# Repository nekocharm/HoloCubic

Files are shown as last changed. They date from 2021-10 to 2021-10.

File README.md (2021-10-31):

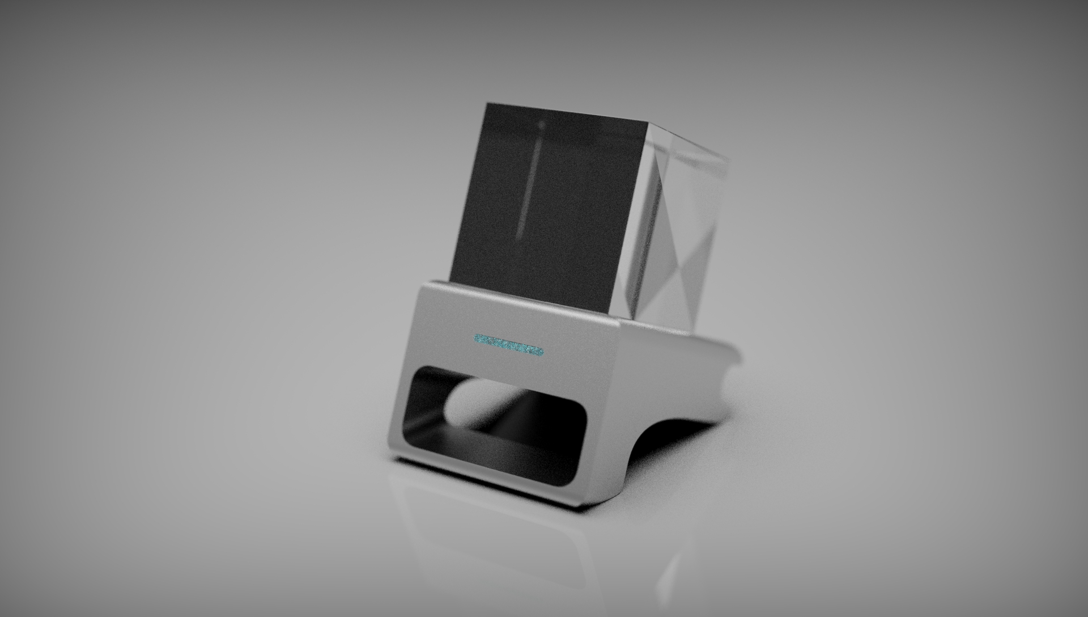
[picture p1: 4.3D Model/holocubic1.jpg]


# HoloCubic--多功能透明显示屏桌面站

**视频介绍：** https://www.bilibili.com/video/BV1VA411p7MD/

## 0. 关于本项目

本项目是从[稚晖君](https://github.com/peng-zhihui/HoloCubic)的基础上编写的，程序写的很乱。以下内容有所删改。

本项目的硬件方案是基于`ESP32PICO-D4`的，乐鑫的一个很实用的MCU芯片，由于采用了SiP封装是的PCBA整板面积能做到一个硬币大小；软件方面主要是基于`lvgl-GUI`库，我移植了ST7789 1.3寸`240x240`分辨率屏幕的显示屏驱动，同时将`MPU6050`作为输入设备通过感应的方式模拟编码器键值来交互。

## 1. 硬件打样说明

**PCB打样的话暂时没发现有啥需要特别注意的。** PCB文件可以直接拿去工厂打样，两层板很便宜，器件BOM的话也都是比较常用的，整板成本在50元以内。

**本项目里只有metal版本的PCB和模型**。我使用了这个版本的模型故删掉了其他版本的模型。

**我觉得RGB没有用就把RGB给去掉了，还把环境光传感器放在了前面，**不过最后我也没用环境光传感器，感觉用途不大，~~我终于知道为什么稚晖君把环境光传感器给去掉了。~~

## 2. 固件编译说明

固件框架主要基于Arduino开发完成，玩过Arduino的基本没有上手难度了，把Firmware/Libraries里面的库安装到Arduino库目录（如果你用的是Arduino IDE的话）即可。

> 我使用的是Visual Studio Code里的platformIO插件。

**然后这里需要修改一个官方库文件才能正常使用：**

首先肯定得安装ESP32的Arduino支持包（百度有海量教程），然后在安装的支持包的`esp32\hardware\esp32\1.0.4\libraries\SPI\src\SPI.cpp`文件中，**修改以下代码中的MISO为26**：

    if(sck == -1 && miso == -1 && mosi == -1 && ss == -1) {
        _sck = (_spi_num == VSPI) ? SCK : 14;
        _miso = (_spi_num == VSPI) ? MISO : 12; // 需要改为26
        _mosi = (_spi_num == VSPI) ? MOSI : 13;
        _ss = (_spi_num == VSPI) ? SS : 15;
这是因为，硬件上连接屏幕和SD卡分别是用两个硬件SPI，其中HSPI的默认MISO引脚是12，而12在ESP32中是用于上电时设置flash电平的，上电之前上拉会导致芯片无法启动，因此我们将默认的引脚替换为26。

> 也可以通过设置芯片熔丝的方式解决这个问题，不过那样的操作是一次性不可逆的，不建议这么玩。

**天气API**用的是心知天气，key我是保存在内存卡里然后读出来。

**内存卡**里具体要放哪些文件可以从程序中看出，内容太多就不放到GitHub上了。

**字体文件**是使用外部字库，可以找自己喜欢的字体用[LvglFontTool](http://www.lfly.xyz/forum.php)转换为bin文件。

## 3. Visual Studio模拟器 & 图片转换脚本

在`Software`文件夹中包含了一个Visual Studio的工程，用VS打开（需要安装C++开发组件）后可以在电脑上模拟LVGL的界面效果，改好之后代码粘贴到Arduino固件那边就可以完成界面移植。

> 这样省的每次修改都要重新交叉编译Arduino的固件，提升开发效率。

`HoloCubic`文件夹下是我用Qt6写的一个上位机软件，可以改WiFi密码等。

> release文件夹里有打包好的软件。

## 4. 关于分光棱镜

我用的时25.4mm x 25.4mm x 25.4mm的棱镜，淘宝应该可以搜到，单个价格80元左右。

分光棱镜的固定比较麻烦，OCA胶水太难粘了，揭下来的时候还弄坏了一个屏幕，我推荐使用UV胶，可以保证没有气泡。

## 5.实物图

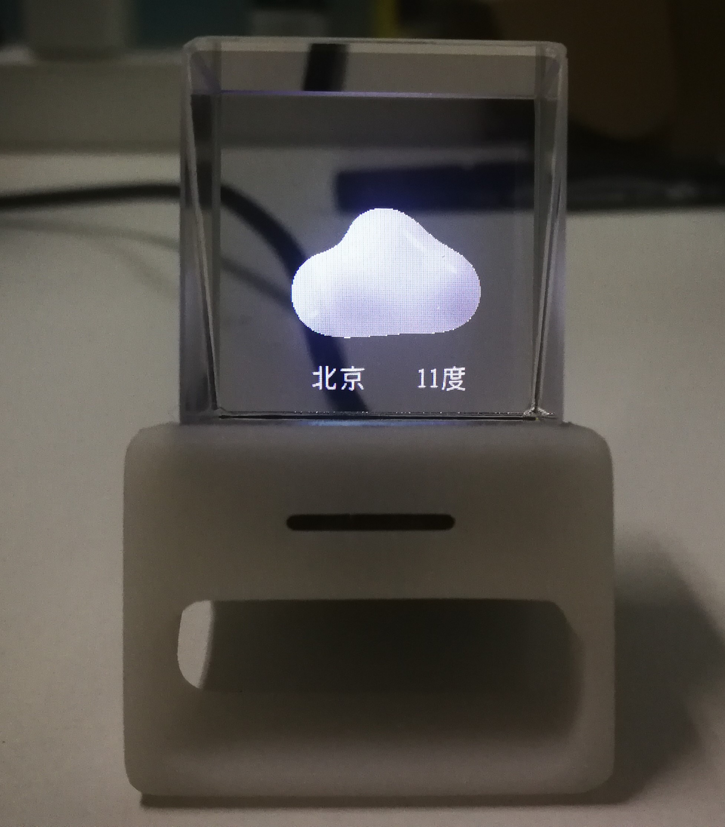
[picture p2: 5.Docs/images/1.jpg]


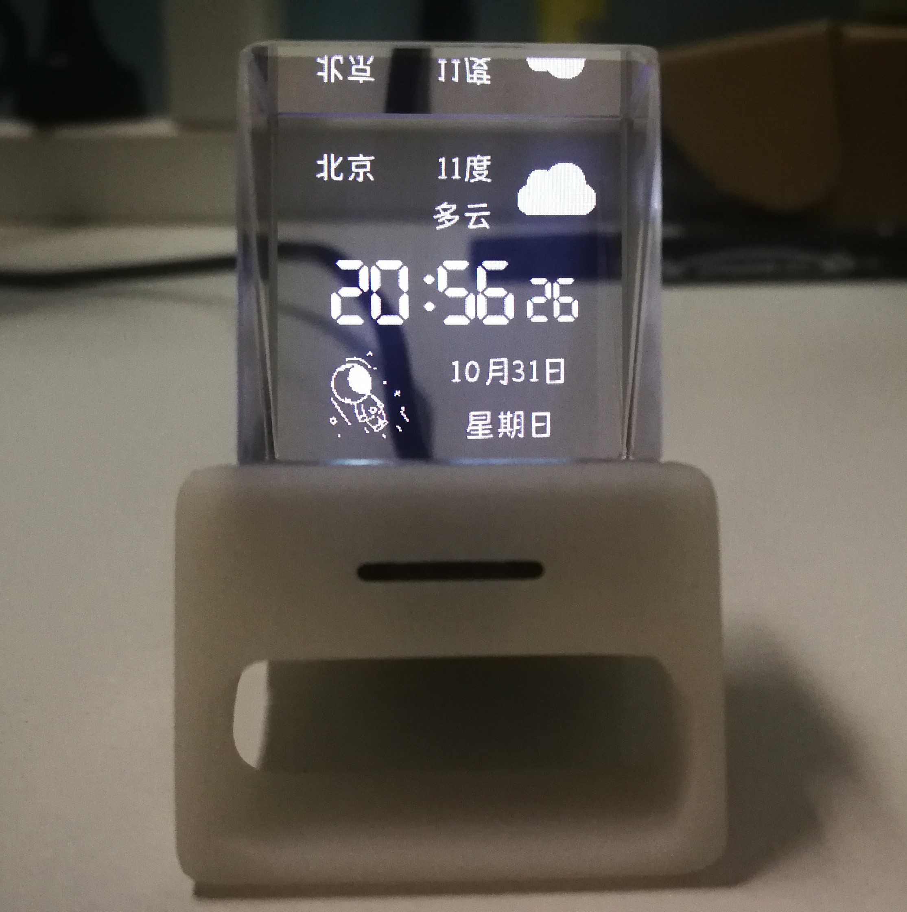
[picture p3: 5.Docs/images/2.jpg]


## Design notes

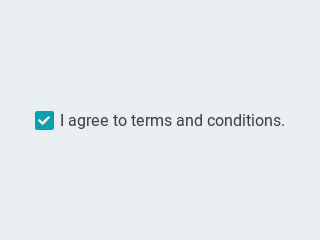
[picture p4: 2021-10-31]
3.Software/LvglSimulator/vs2019_proj/lv_examples/src/lv_ex_widgets/lv_ex_checkbox/lv_ex_checkbox_1.png

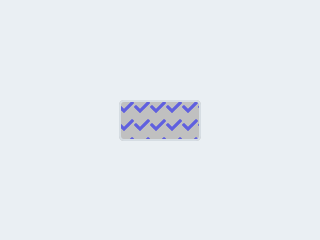
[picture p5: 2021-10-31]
3.Software/LvglSimulator/vs2019_proj/lv_examples/src/lv_ex_style/lv_ex_style_5.png

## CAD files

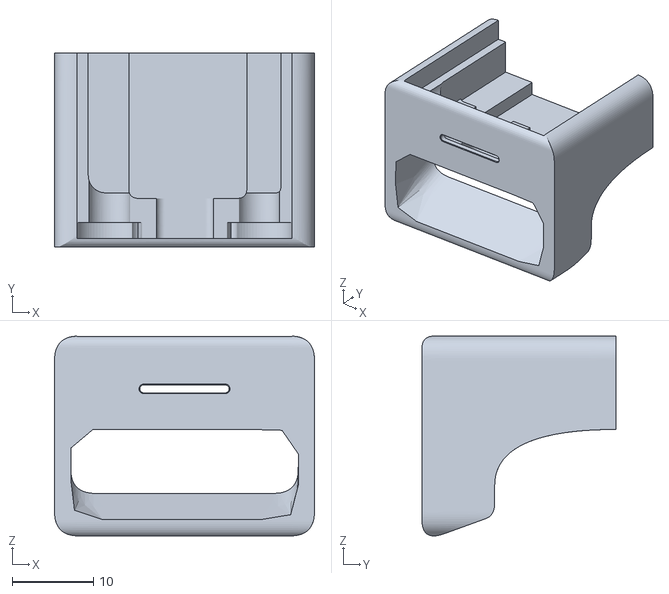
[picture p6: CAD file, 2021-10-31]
4.3D Model/1.stl
32.0 x 23.9 x 24.6

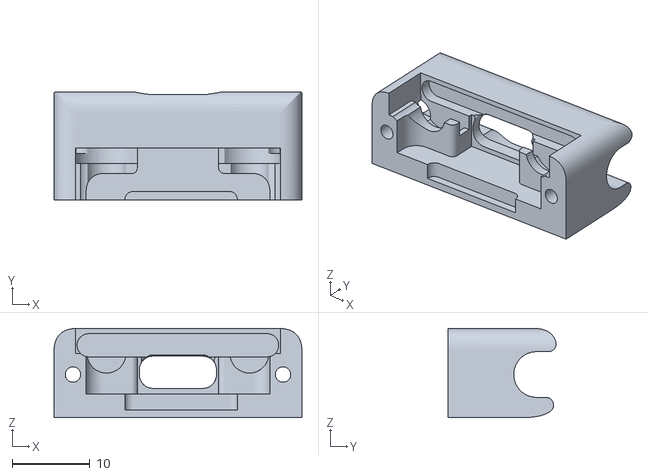
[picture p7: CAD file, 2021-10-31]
4.3D Model/2.stl
32.0 x 14.0 x 11.5

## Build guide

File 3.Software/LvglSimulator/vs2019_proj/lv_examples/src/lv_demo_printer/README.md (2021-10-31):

# Printer demo

## Overview
A printer example created with LVGL. This demo is optmized for 800x480 resolution and among many others it demonstrates custom theme creation, style transitions and animations. 

The demo uses some images with 32 bit color depth they require ~1.6 MB flash. With 16 bit color depth ~900KB is required for the images.

Printer demo with LVGL embedded GUI library

## Run the demo
- In `lv_ex_conf.h` set `LV_USE_DEMO_PRINTER 1`
- After `lv_init()` and initializing the drivers call `lv_demo_printer()`

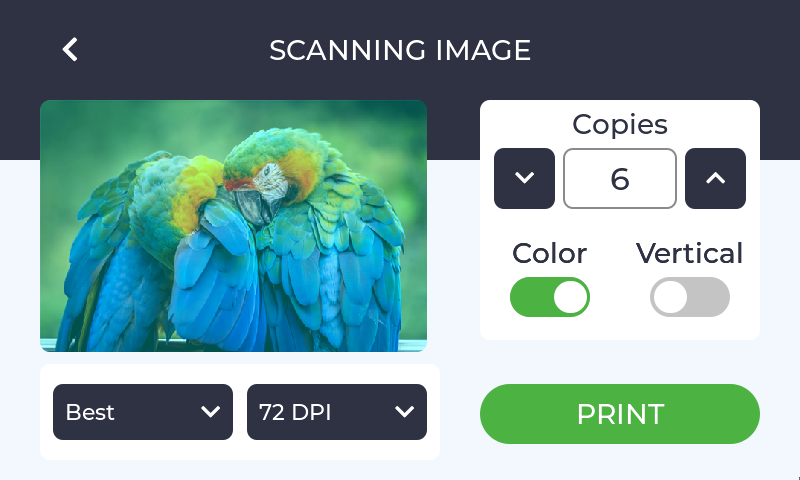
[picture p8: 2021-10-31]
3.Software/LvglSimulator/vs2019_proj/lv_examples/src/lv_demo_printer/screenshot1.png

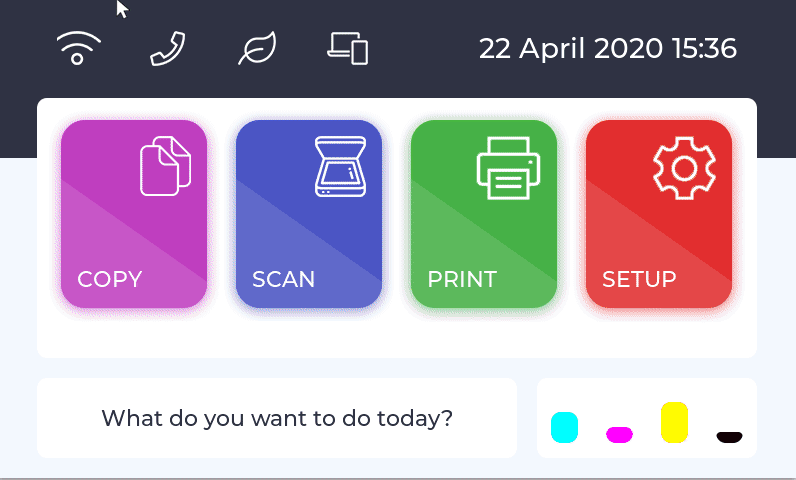
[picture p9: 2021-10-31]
3.Software/LvglSimulator/vs2019_proj/lv_examples/src/lv_demo_printer/screenshot1.gif

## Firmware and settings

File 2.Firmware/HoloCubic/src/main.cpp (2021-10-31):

#include <Arduino.h>
#include "display.h"
#include "imu.h"
#include "ambient.h"
#include "network.h"
#include "sd_card.h"
#include "lv_port_indev.h"
#include "lv_port_fatfs.h"
#include "gui_guider.h"
#include <TFT_eSPI.h>
#include "time.h"
#include <ESP32Time.h>

// 函数声明
bool getWeather();

/*** Component objects ***/
Display screen;  //屏幕显示
IMU mpu;  //MPU6050
SdCard tf;  // 内存卡
Network wifi;  //网络ambient
Ambient ambient; //环境光传感器
lv_ui guider_ui;  //GUI

// 更换页面
uint8_t button_state=0;
uint8_t page_num=0;
//static char buf[100];

//float duty=0;

/*** 全局变量 ***/
// 天气位置

extern String location;
extern String key;
String _location="";
// 时间
struct tm timeinfo;
ESP32Time rtc;

// 天气变量
extern String temperature;
extern String weather;
extern uint8_t weather_code;

// wifi连接
String ssid;
String password;
String _ssid;
String _password;


// 备忘录
String text="";
extern lv_obj_t* label_text;

boolean wifi_status=false;


// 对时任务，天气任务和调光任务

uint16_t time_num=0;
void user_task(lv_task_t * task){
    /*Use the user_data*/
    uint16_t* user_data=(uint16_t*)task->user_data;
    //duty=ambient.getLux()/30;
    //duty = constrain(duty, 0, 0.3);
    //screen.setBackLight(duty+0.4);  //设置背光
    (*user_data)++;
    if(*user_data==600){
        (*user_data)=0;
        if(wifi_status){
            configTime(28800, 0, "ntp3.aliyun.com");
            if(getLocalTime(&timeinfo)){
                rtc.setTimeStruct(timeinfo); 
            }
            getWeather();
        }
        
    }
}

void setup_task(void){
    lv_task_t * task_user = lv_task_create(user_task, 1000, LV_TASK_PRIO_MID, &time_num);
    lv_task_ready(task_user);
    
}



void setup()
{
    Serial.begin(115200);  //打开串口

    /*** Init screen ***/
    screen.init();   //初始化屏幕
    screen.setBackLight(0.5);  //设置背光
    ambient.init(ONE_TIME_H_RESOLUTION_MODE);  //初始化环境光传感器 采样时间125
   
    /*** Init IMU as input device ***/
    lv_port_indev_init();  //初始化输入设备
    mpu.init();  //初始化加速度计

    delay(1000);

    /*** Init micro SD-Card ***/
    tf.init();  //初始化tf卡
    lv_fs_if_init();  //初始化 文件系统

    /*** 设置WiFi ***/
    ssid = tf.readFileLine("/wifi.txt", 1);        // line-1 for WiFi ssid
    _ssid = ssid;
    password = tf.readFileLine("/wifi.txt", 2);    // line-2 for WiFi password
    _password=password;
    //tf.writeFile("/text.txt","aaaa\n");
    text=tf.readFileLine("/text.txt",1);
    //Serial.println(ssid);
    //Serial.println(password);

    location = tf.readFileLine("/location.txt",1);
    _location = location;
    key = tf.readFileLine("/weather.txt",2);
    
    /*** Read WiFi info from SD-Card, then scan & connect WiFi ***/
    wifi.init(ssid, password);
    wifi_status=wifi.status();
    // 初始化时间
    if(wifi_status){
        configTime(28800, 0, "ntp3.aliyun.com");
        if(getLocalTime(&timeinfo)){
            rtc.setTimeStruct(timeinfo); 
        }
    }
    Serial.println("gettime done");
    /*** Inflate GUI objects ***/
    setup_ui(&guider_ui);
    Serial.println("setup_ui done");
    setup_task();
    Serial.println("setup_task done");

    if(wifi_status){
        Serial.println("status");
        getWeather();
    }

}

int frame_id = 1;

// 串口缓冲变量
String comdata = "";

void loop()
{
    // run this as often as possible
    screen.routine();

    // 200 means update IMU data every 200ms
    mpu.update(200);
    //Serial.println(mpu.getAccelX());
    //Serial.println("hello");

    switch (button_state)
    {
    case 1:
        if(page_num>0)
            page_num--;
            lv_tabview_set_tab_act(tabview, page_num, LV_ANIM_OFF);
        break;
    case 2:
        if(page_num<3)
            page_num++;
            lv_tabview_set_tab_act(tabview, page_num, LV_ANIM_OFF);
        break;
    
    default:
        break;
    }

    //Serial.println(ambient.getLux());
    while (Serial.available() > 0){
        comdata += char(Serial.read());
        delay(2);
    }
    if (comdata.length() > 0)
    {  
        Serial.println(comdata); 
        if(comdata.startsWith("ssid")){
            comdata=comdata.substring(4,comdata.length());
            Serial.println(comdata);
            ssid=comdata;
        }
        if(comdata.startsWith("pswd")){
            comdata=comdata.substring(4,comdata.length());
            Serial.println(comdata);
            password = comdata;
        }
        if(comdata.startsWith("weat")){
            comdata=comdata.substring(4,comdata.length());
            Serial.println(comdata);
            location = comdata;
        }
        if(comdata.startsWith("text")){
            comdata=comdata.substring(4,comdata.length());
            Serial.println(comdata);
            if(!text.equals(comdata)){
                text=comdata;
                tf.writeFile("/text.txt",(text+"\n").c_str());
                lv_label_set_text(label_text, text.c_str());
            }
        }
        comdata = "";
    }

    if(!location.equals(_location)){
        _location=location;
        getWeather();
        tf.writeFile("/location.txt",(location+"\n").c_str());
        lv_label_set_text(weather_label_location, location.c_str());
        lv_label_set_text(label_city, location.c_str());
    }
    if(!ssid.equals(_ssid)&&!password.equals(_password)){
        _ssid=ssid;
        _password = password;
        tf.writeFile("/wifi.txt",(ssid+"\n"+password+"\n").c_str());
        wifi.init(ssid, password);
        
    }
    //delay(20);
    wifi_status=wifi.status();
    delay(10);
}

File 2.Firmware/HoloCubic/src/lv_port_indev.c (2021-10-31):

/**
 * @file lv_port_indev_templ.c
 *
 */

 /*Copy this file as "lv_port_indev.c" and set this value to "1" to enable content*/

/*********************
 *      INCLUDES
 *********************/
#include "lv_port_indev.h"

static void encoder_init(void);
static bool encoder_read(lv_indev_drv_t* indev_drv, lv_indev_data_t* data);
static void encoder_handler(void);


lv_indev_t* indev_encoder;

int32_t encoder_diff;
lv_indev_state_t encoder_state;


void lv_port_indev_init(void)
{
	/* Here you will find example implementation of input devices supported by LittelvGL:
	 *  - Touchpad
	 *  - Mouse (with cursor support)
	 *  - Keypad (supports GUI usage only with key)
	 *  - Encoder (supports GUI usage only with: left, right, push)
	 *  - Button (external buttons to press points on the screen)
	 *
	 *  The `..._read()` function are only examples.
	 *  You should shape them according to your hardware
	 */


	lv_indev_drv_t indev_drv;


	/*------------------
	 * Encoder
	 * -----------------*/

	 /*Initialize your encoder if you have*/
	encoder_init();

	/*Register a encoder input device*/
	lv_indev_drv_init(&indev_drv);
	indev_drv.type = LV_INDEV_TYPE_ENCODER;
	indev_drv.read_cb = encoder_read;
	indev_encoder = lv_indev_drv_register(&indev_drv);

	/* Later you should create group(s) with `lv_group_t * group = lv_group_create()`,
	 * add objects to the group with `lv_group_add_obj(group, obj)`
	 * and assign this input device to group to navigate in it:
	 * `lv_indev_set_group(indev_encoder, group);` */


}

/**********************
 *   STATIC FUNCTIONS
 **********************/


 /*------------------
  * Encoder
  * -----------------*/

  /* Initialize your keypad */
static void encoder_init(void)
{
	/*Your code comes here*/
}

/* Will be called by the library to read the encoder */
static bool encoder_read(lv_indev_drv_t* indev_drv, lv_indev_data_t* data)
{

	data->enc_diff = encoder_diff;
	data->state = encoder_state;

	encoder_diff = 0;
	/*Return `false` because we are not buffering and no more data to read*/
	return false;
}

/*Call this function in an interrupt to process encoder events (turn, press)*/
static void encoder_handler(void)
{
	/*Your code comes here*/

	encoder_diff += 0;
	encoder_state = LV_INDEV_STATE_REL;
}
